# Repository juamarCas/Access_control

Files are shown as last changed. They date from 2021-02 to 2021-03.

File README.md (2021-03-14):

# Access Control
This project consist on a access control system. It uses microcontroller ESP8266 for internet connection, MQTT as my data transfer protocol, NodeJS as the backend programming Language, Express as the framework for the API and MySQL as the Database.</br>

The architecture of the complete project looks like this: </br>

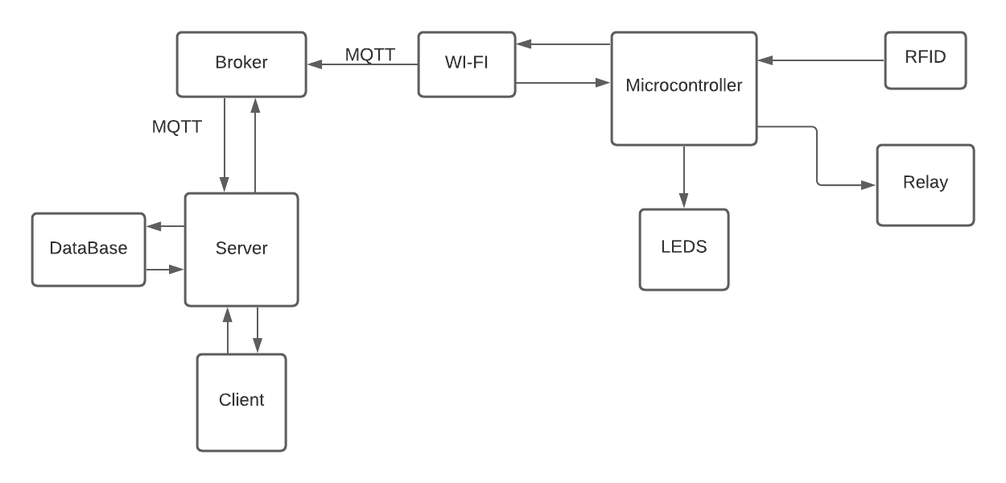
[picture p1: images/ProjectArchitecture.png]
all text


# Dockerizing
be executed with containers, for this, there is the _docker-compose.yml_ file, just copy the content of app.env.example and paste it in a new file called app.env same to the db.env.example and broker.env.example, then fill the data needed in both files, build the two Dockerfile that are in DataBase and webApp and then run the docker-compose.</br>
In the docker-compose file describes that the image used for the app is nodeapp, so be sure when the image is builded is named as that, or change its name as your needs, same for the image of the database.

# Directory
In this section I discribe briefly what is each folder.</br>

## Access_Control
In this folder is the microcontroller project and schematics, is programmed using the PIO IDE.</br>

## DataBase
Thise folder contains the sql file for creating the tables needed.</br>

## HW_Design
This folder includes the KiCad project for the circuit.</br>

## Web-client
This folder includes the frontend of the projects, hasn't started yet this part.</br>

## webApp
This folder includes the NodeJS code for the backend.</br>

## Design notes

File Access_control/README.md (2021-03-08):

# Access control circuit
This section shows the firmware of the microcontroller part of the project.</br>
Important note: The circuit uses a relay to activate the secure system, this is a security vulnerability, it can be brokenn with a magnetic attack, this problem can be solved changing the relay for another component like a transistor.</br>

## Running the circuit
1. There is a file called SecretsExample.h, create another file called secrets.h and copy the content from SecretsExample.h to secrets.h, then fill the parameters.
2. The file should look something like: 
```
#ifndef SECRETS_H   
#define SECRETS_H
#define _SSID "your ssid"
#define _PASS "your pass"
#define MQTT_SERVER "mqtt host/ip"
#define MQTT_PORT 1883
#define MQTT_SUBSCRIBE_TOPIC "bld1/apt6/room1/acc"
#define MQTT_PUBLIS_TOPIC "bld1/apt6/room1"
#define MQTT_USER "user_auth"
#define MQTT_PASS "pass_auth"
#define DEBUG 1
#endif
```
</br>
Important note: If you are not using MQTT access control, please skip MQTT_USER and MQTT_PASS, and in the main.cpp in _reconnect()_ method, delete the two parameters that are related to this definition.

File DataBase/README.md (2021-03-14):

# DataBase
MySQL version 5.7 </br>
Important Note: Using docker is not necessary, use another host of your needs.</br>

## Database design 

MySQL is the database used to store information and it follows this simplified design: </br>
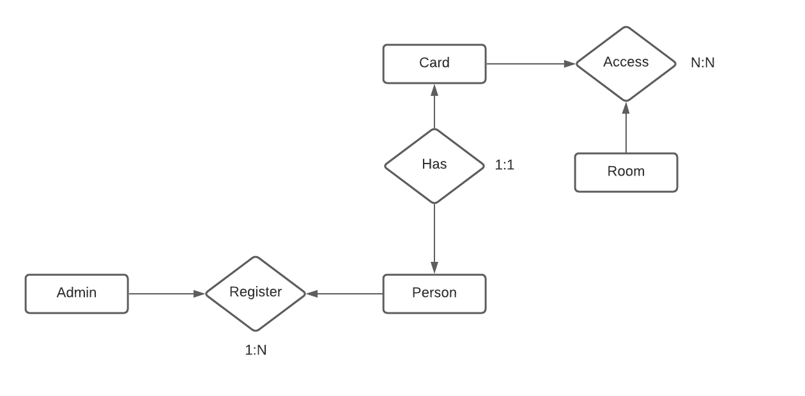
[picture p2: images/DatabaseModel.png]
all text Database model


## Tables
Important note:  the tables _mqtt\_user_ and _mqtt\_acl_ are for the EMQX MySQL access control plugin, if you are not using EMQX or the MySQL EQMX plugin, please skip those tables. For more information go to their [Documentation](https://docs.emqx.io/en/broker/latest/advanced/acl-mysql.html#mysql-connection-information "MySql access control plugin documentation").</br>

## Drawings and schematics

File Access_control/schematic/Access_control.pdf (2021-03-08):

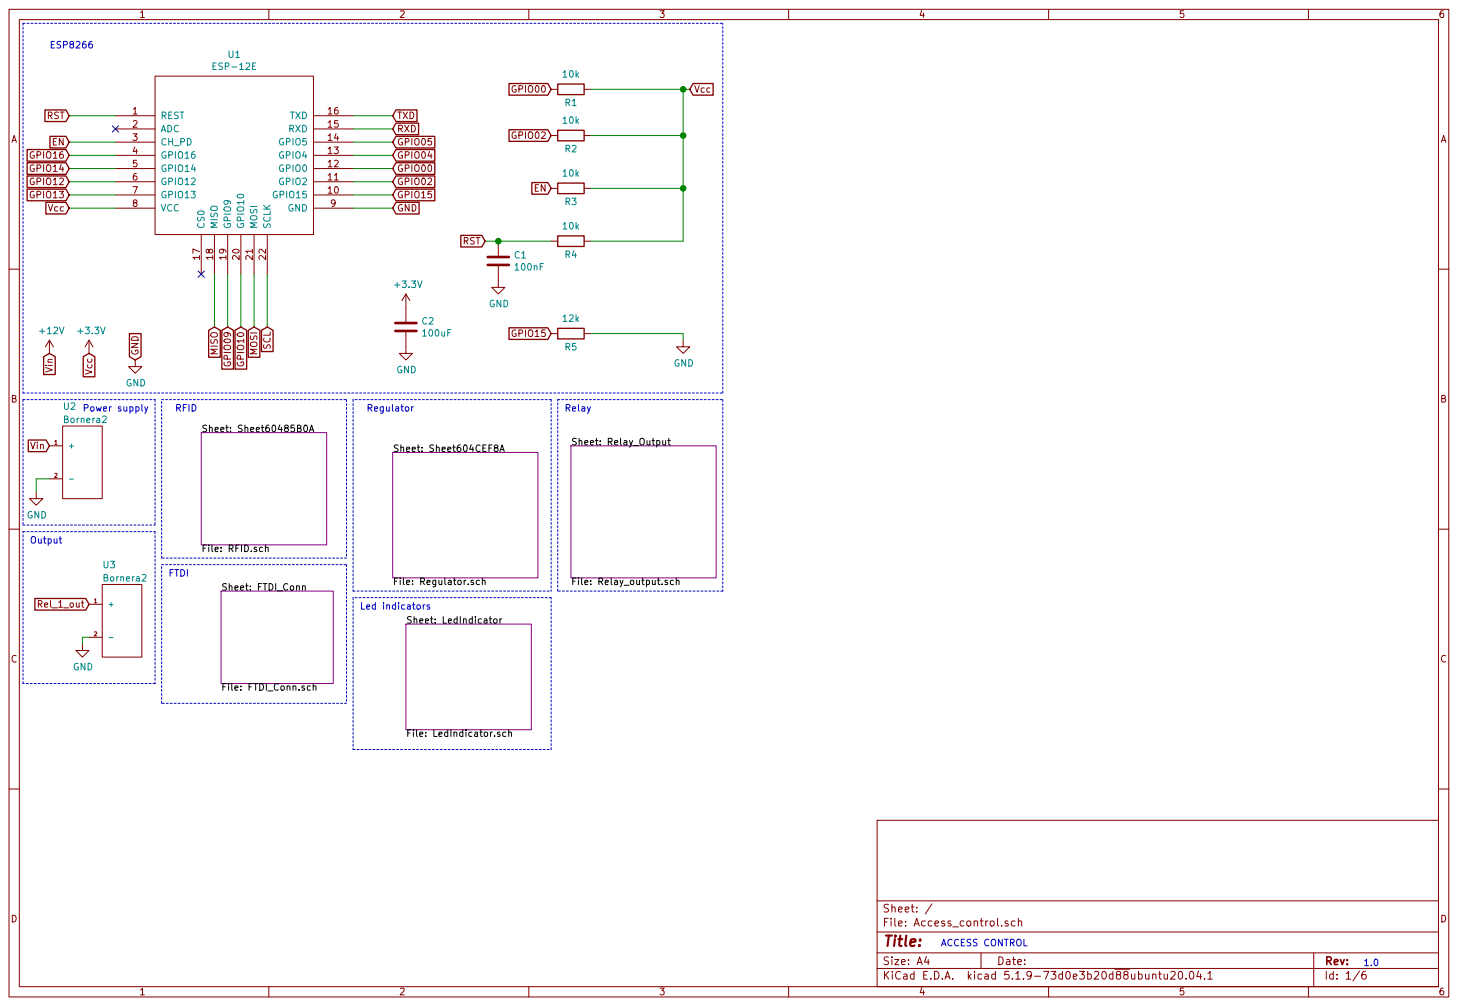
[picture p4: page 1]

File: Relay_output.sch Sheet: LedIndicator File: LedIndicator.sch GND

File: Regulator.sch Sheet: FTDI_Conn File: FTDI_Conn.sch Sheet: Sheet60485B0A

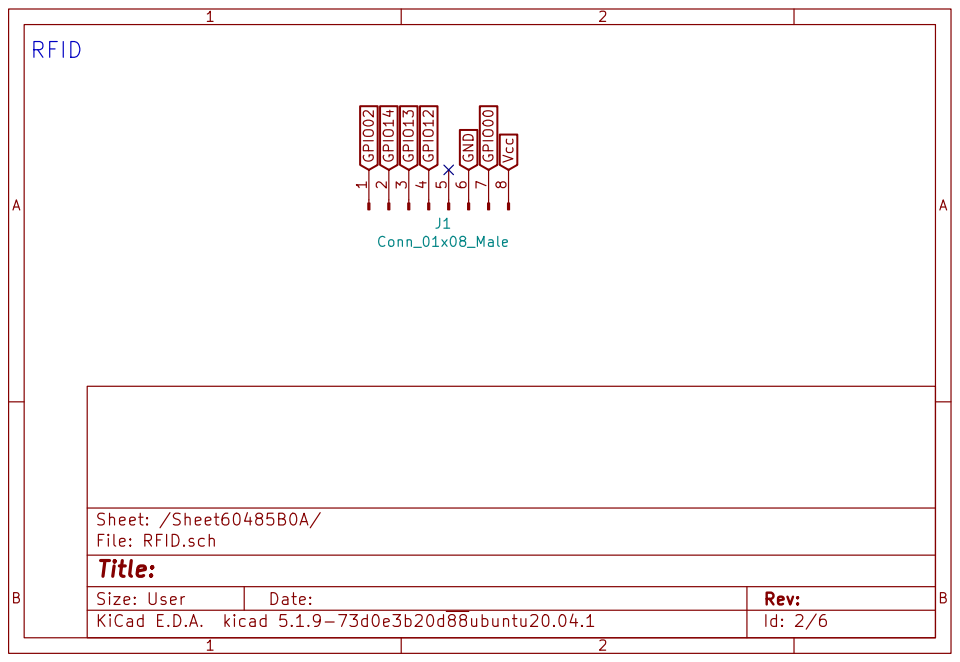
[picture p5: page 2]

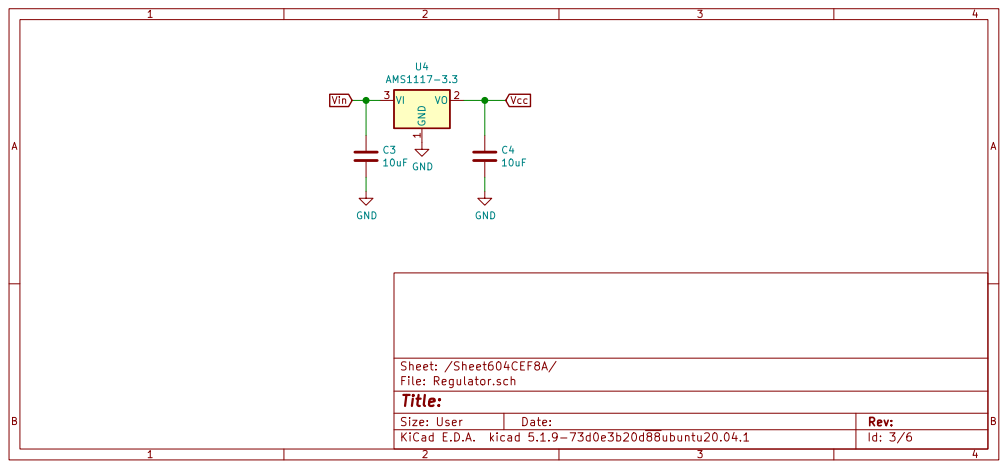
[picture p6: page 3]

File: Regulator.sch Sheet: /Sheet604CEF8A/ GNDGND

1 VO 2 VI 3 U4 AMS1117-3.3 GND GND

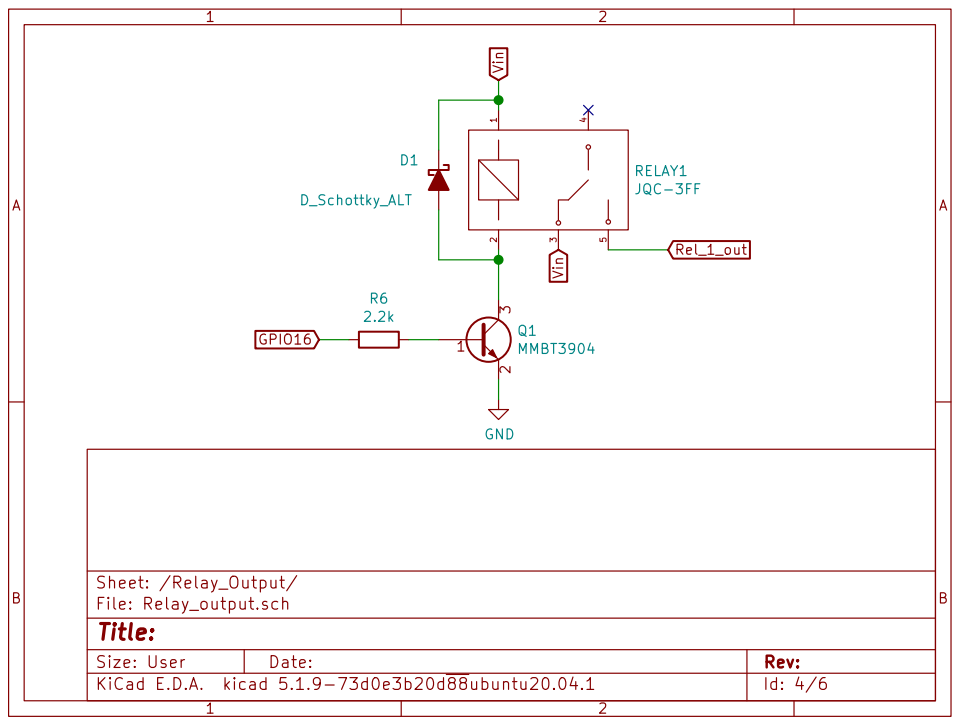
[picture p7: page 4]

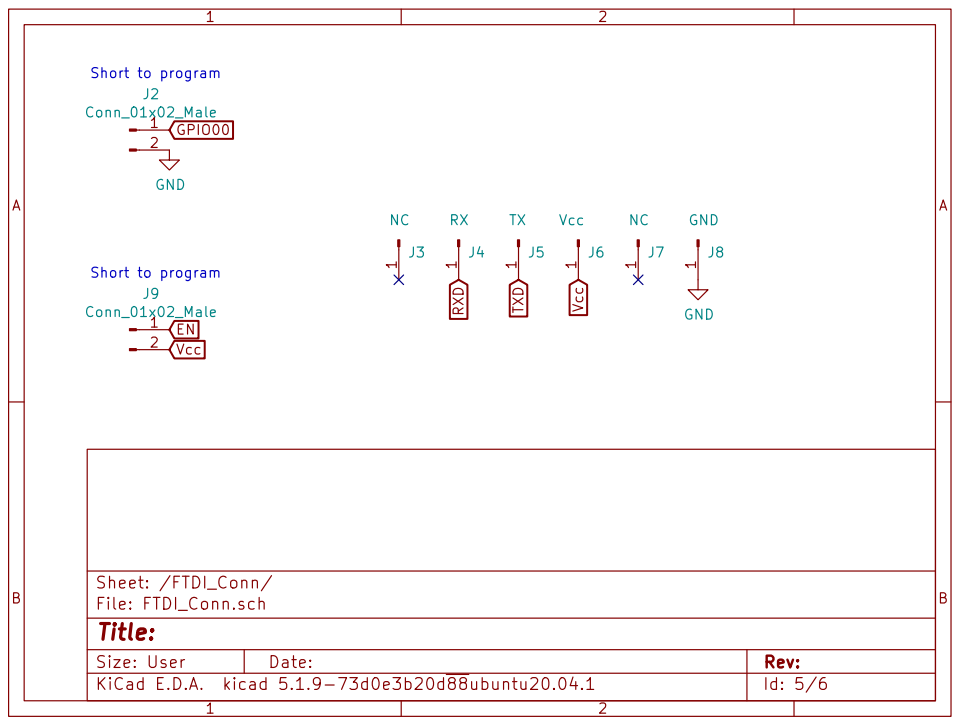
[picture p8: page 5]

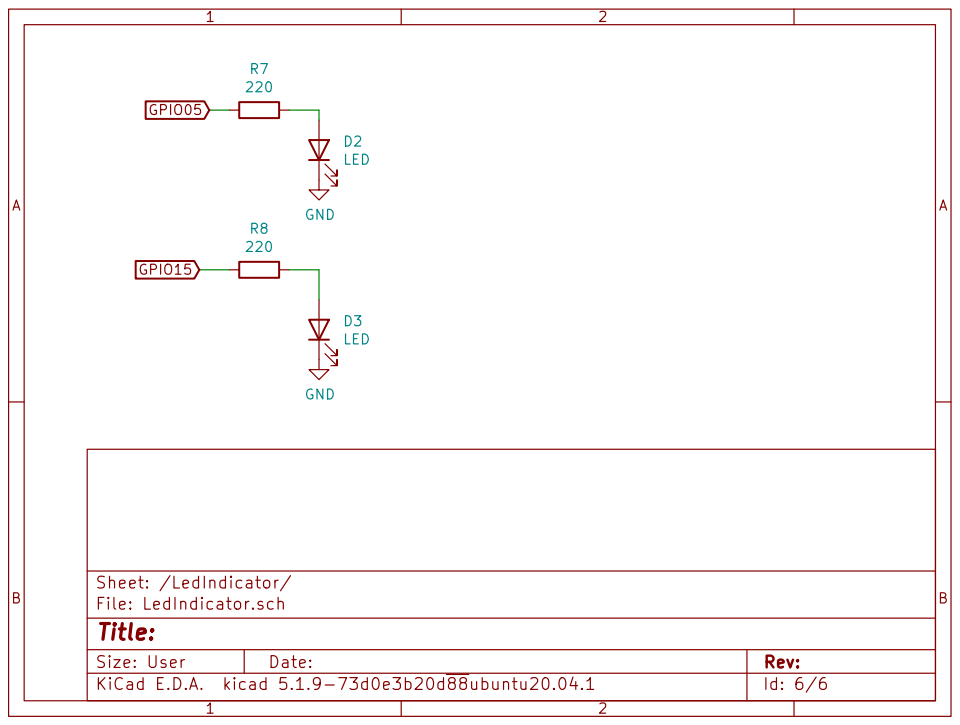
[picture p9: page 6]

Id: 6/6 Title: File: LedIndicator.sch Sheet: /LedIndicator/ R7

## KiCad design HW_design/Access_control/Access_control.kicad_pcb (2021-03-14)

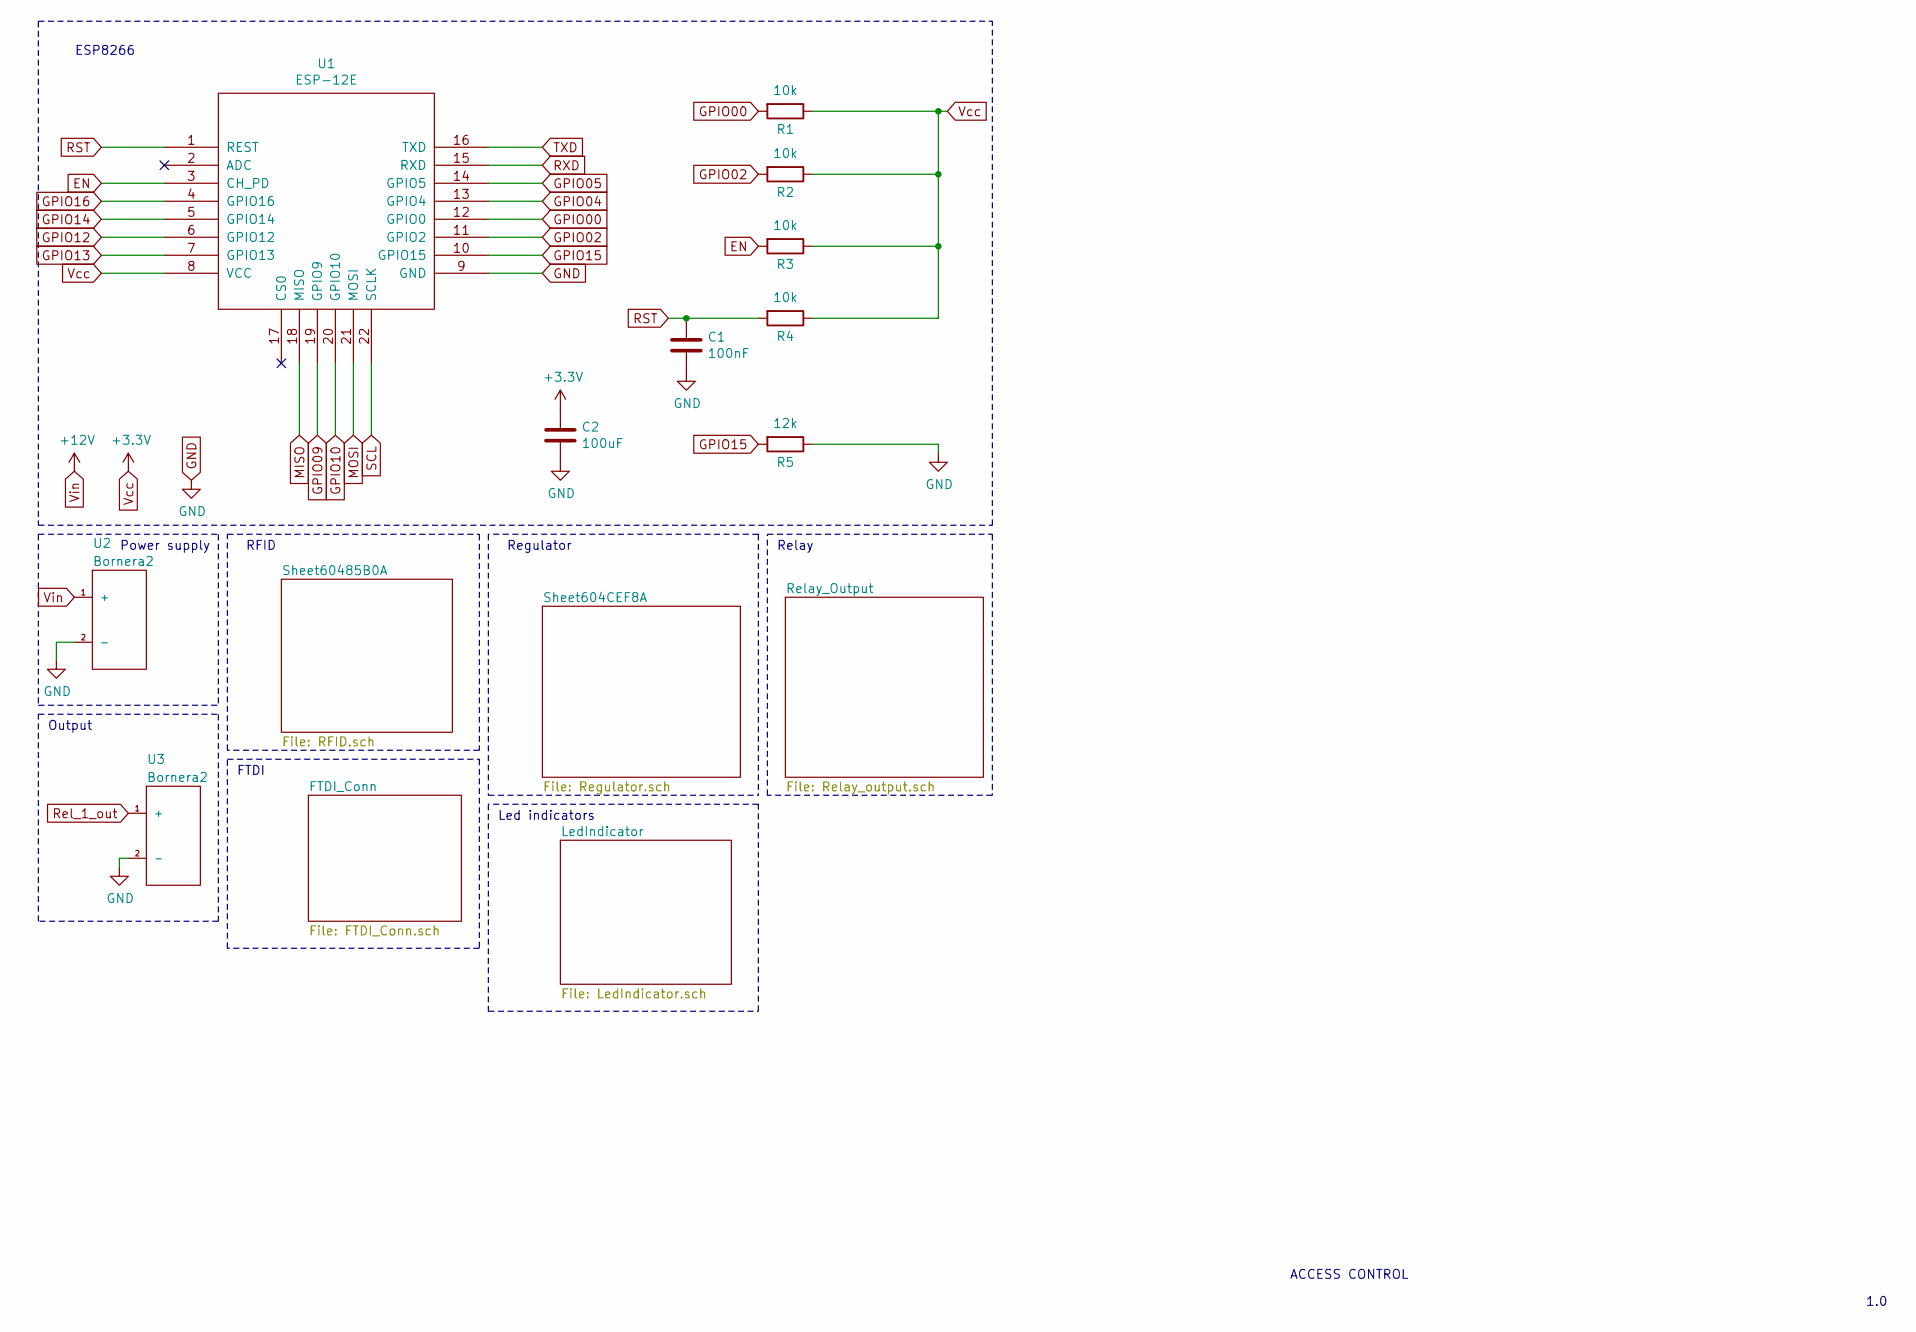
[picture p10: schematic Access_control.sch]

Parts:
C1: 100nF; C_1206_3216Metric
C2: 100uF; C_1206_3216Metric
R1, R2, R3, R4: 10k; R_0805_2012Metric
R5: 12k; R_0805_2012Metric
U1: ESP-12E; C_WiFiModule
U2, U3: Bornera2; Bronera_2

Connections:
EN: R3.2, U1.3 (CH_PD); also elsewhere on the board
GND: C1.2, C2.2, R5.1, U1.9 (GND), U2.2 (-), U3.2 (-); also elsewhere on the board
GPIO00: R1.2, U1.12 (GPIO0); also elsewhere on the board
GPIO02: R2.2, U1.11 (GPIO2); also elsewhere on the board
GPIO04: U1.13 (GPIO4)
GPIO05: U1.14 (GPIO5); also elsewhere on the board
GPIO09: U1.19 (GPIO9)
GPIO10: U1.20 (GPIO10)
GPIO12: U1.6 (GPIO12); also elsewhere on the board
GPIO13: U1.7 (GPIO13); also elsewhere on the board
GPIO14: U1.5 (GPIO14); also elsewhere on the board
GPIO15: R5.2, U1.10 (GPIO15); also elsewhere on the board
GPIO16: U1.4 (GPIO16); also elsewhere on the board
MISO: U1.18 (MISO)
MOSI: U1.21 (MOSI)
RST: C1.1, R4.2, U1.1 (REST)
RXD: U1.15 (RXD); also elsewhere on the board
Rel_1_out: U3.1 (+); also elsewhere on the board
SCL: U1.22 (SCLK)
TXD: U1.16 (TXD); also elsewhere on the board
Vcc: C2.1, R1.1, R2.1, R3.1, R4.1, U1.8 (VCC); also elsewhere on the board
Vin: U2.1 (+); also elsewhere on the board

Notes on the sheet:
ESP8266
RFID
Power supply
Regulator
ACCESS CONTROL
1.0
Relay
Output
FTDI
Led indicators

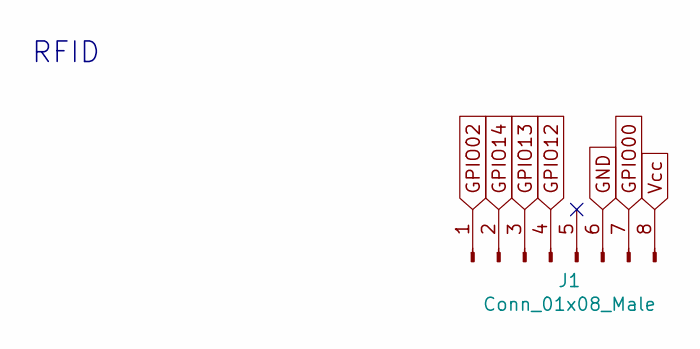
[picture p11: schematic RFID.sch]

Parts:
J1: Conn_01x08_Male; PinHeader_1x08_P2.54mm_Vertical

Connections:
GND: J1.6; also elsewhere on the board
GPIO00: J1.7; also elsewhere on the board
GPIO02: J1.1; also elsewhere on the board
GPIO12: J1.4; also elsewhere on the board
GPIO13: J1.3; also elsewhere on the board
GPIO14: J1.2; also elsewhere on the board
Vcc: J1.8; also elsewhere on the board

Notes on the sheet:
RFID

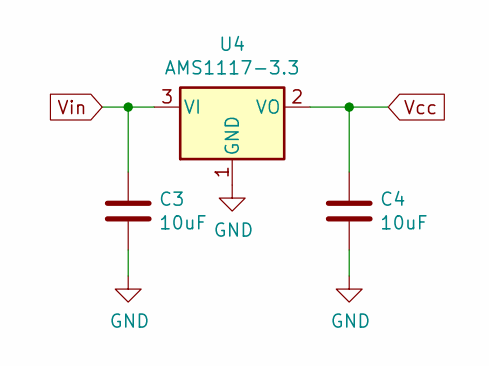
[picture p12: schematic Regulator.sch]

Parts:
C3, C4: 10uF; C_1206_3216Metric
U4: AMS1117-3.3; SOT-223-3_TabPin2

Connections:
GND: C3.2, C4.2, U4.1 (GND); also elsewhere on the board
Vcc: C4.1, U4.2 (VO); also elsewhere on the board
Vin: C3.1, U4.3 (VI); also elsewhere on the board

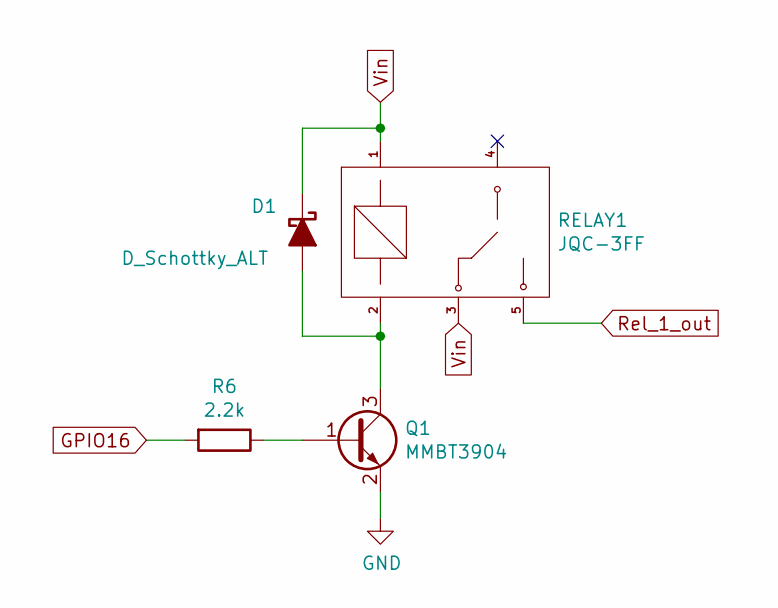
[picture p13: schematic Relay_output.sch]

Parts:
D1: D_Schottky_ALT; SMD_DIODE_4.6mmx2.90
Q1: MMBT3904; SOT-23
R6: 2.2k; R_0805_2012Metric
RELAY1: JQC-3FF; Relay

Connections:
GND: Q1.2 (E); also elsewhere on the board
GPIO16: R6.2; also elsewhere on the board
unnamed: D1.2 (A), Q1.3 (C), RELAY1.2
unnamed: Q1.1 (B), R6.1
Rel_1_out: RELAY1.5; also elsewhere on the board
Vin: D1.1 (K), RELAY1.1, RELAY1.3; also elsewhere on the board

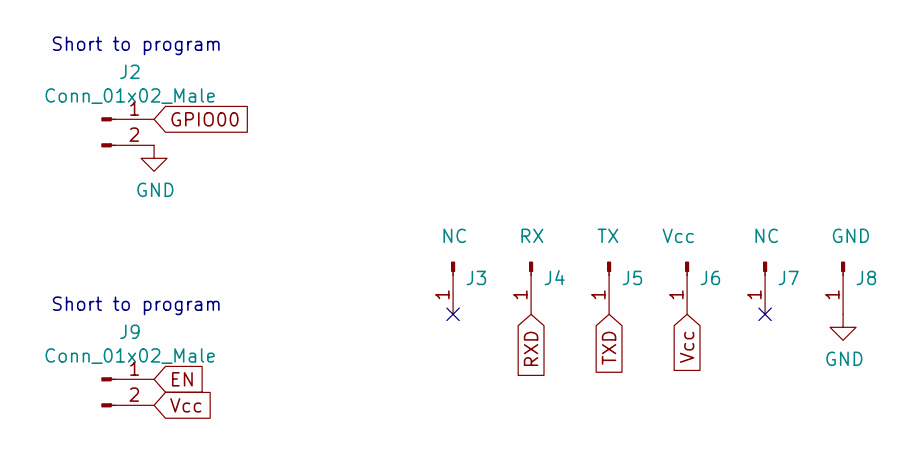
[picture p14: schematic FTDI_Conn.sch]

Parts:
J2, J9: Conn_01x02_Male; PinHeader_1x02_P2.54mm_Vertical
J3, J7: NC; PinHeader_1x01_P2.54mm_Vertical
J4: RX; PinHeader_1x01_P2.54mm_Vertical
J5: TX; PinHeader_1x01_P2.54mm_Vertical
J6: Vcc; PinHeader_1x01_P2.54mm_Vertical
J8: GND; PinHeader_1x01_P2.54mm_Vertical

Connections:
EN: J9.1; also elsewhere on the board
GND: J2.2, J8.1; also elsewhere on the board
GPIO00: J2.1; also elsewhere on the board
RXD: J4.1; also elsewhere on the board
TXD: J5.1; also elsewhere on the board
Vcc: J6.1, J9.2; also elsewhere on the board

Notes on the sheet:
Short to program

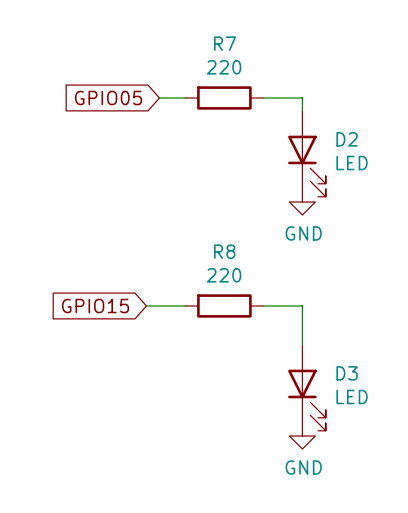
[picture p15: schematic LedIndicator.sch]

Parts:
D2, D3: LED; D_1206_3216Metric
R7, R8: 220; R_0805_2012Metric

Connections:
GND: D2.1 (K), D3.1 (K); also elsewhere on the board
GPIO05: R7.2; also elsewhere on the board
GPIO15: R8.2; also elsewhere on the board
unnamed: D2.2 (A), R7.1
unnamed: D3.2 (A), R8.1

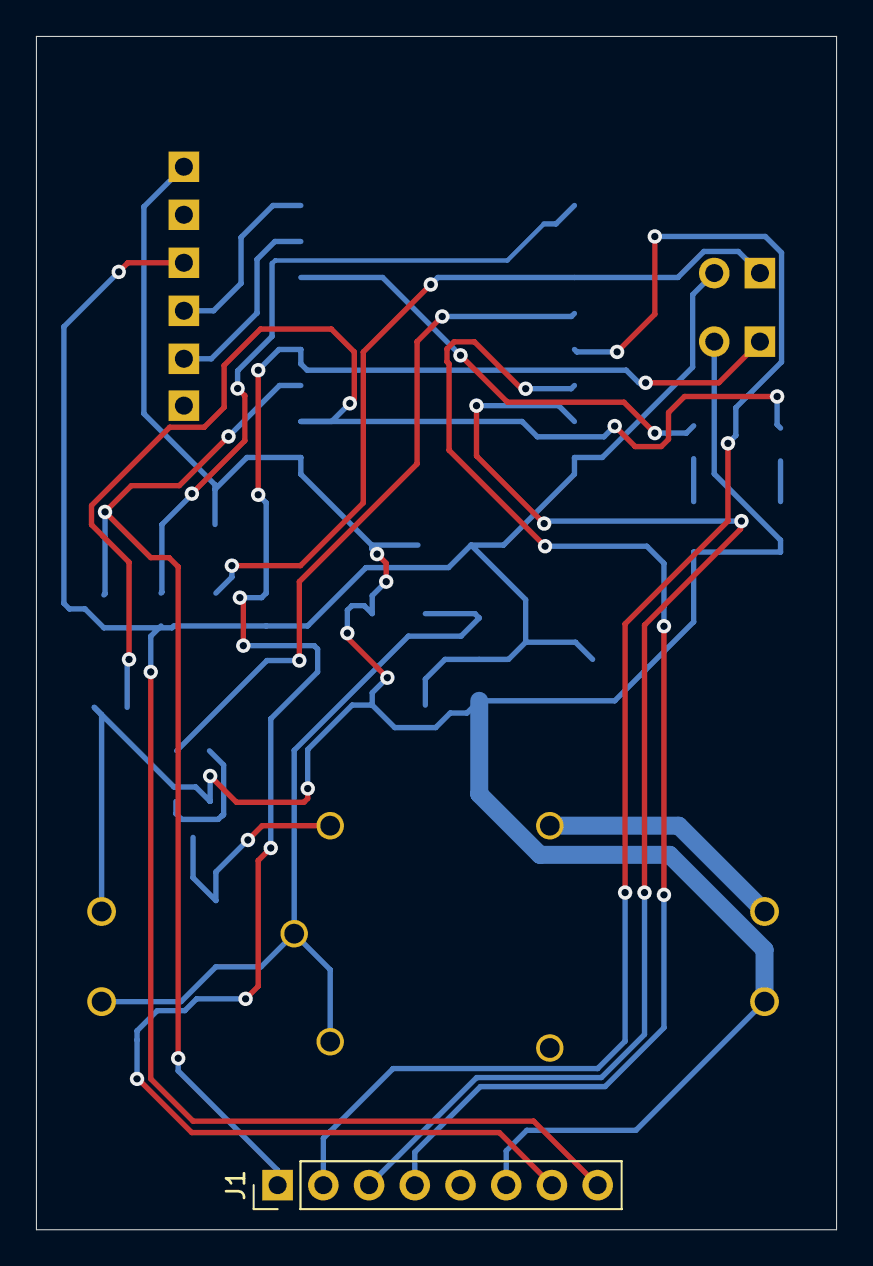
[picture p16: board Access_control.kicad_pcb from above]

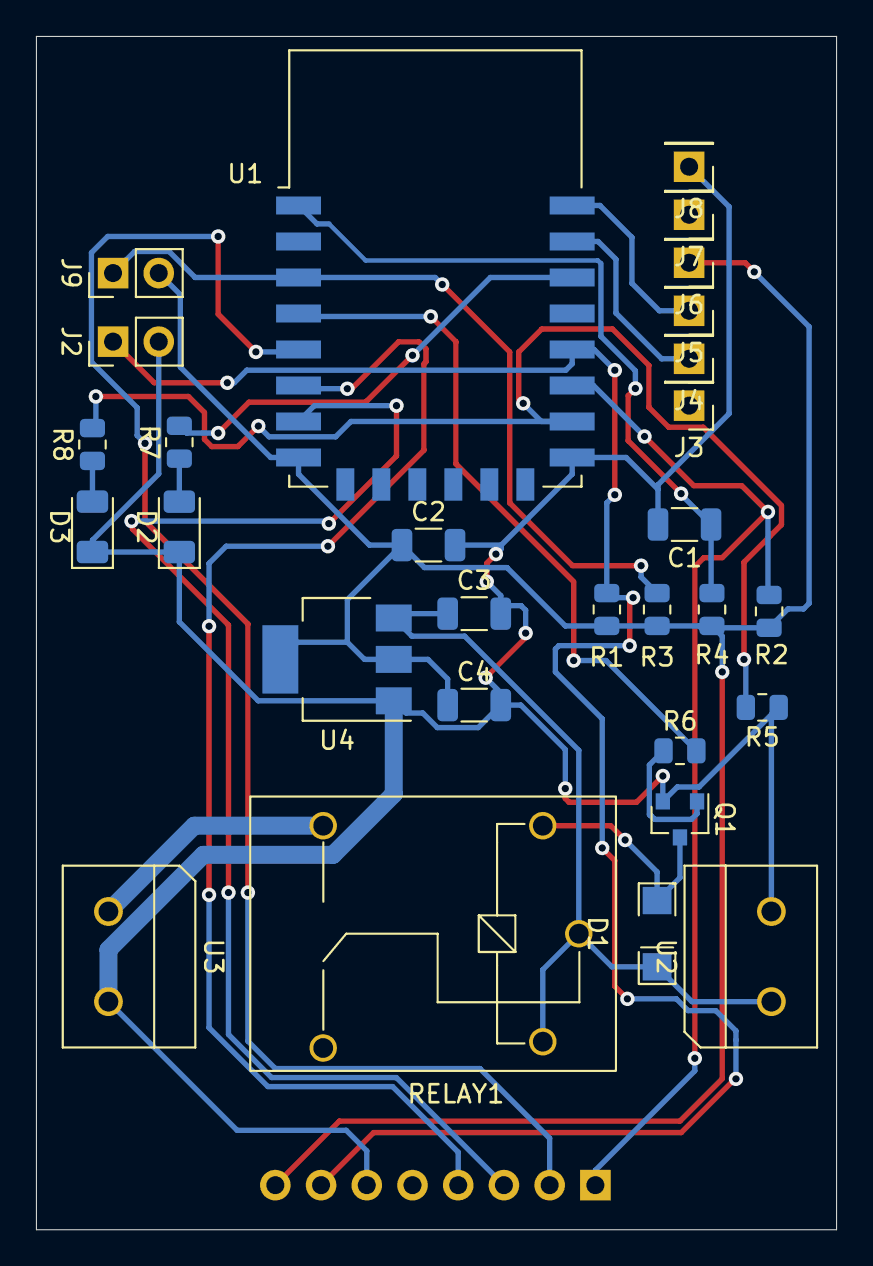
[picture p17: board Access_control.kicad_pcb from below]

Board: 2 copper layers, 44.4 x 66.3 mm, 30 parts (29 on the bottom side), 20 nets.

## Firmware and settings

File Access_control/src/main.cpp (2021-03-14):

#define _SSPIN D4
#define _RSTPIN D3
#define _ACCESS_DENIED_LED D1
#define _ACCESS_GRANTED_LED D0
#define _ACCESS_RELAY_PIN D0
#define DEBUG 1 //please, when you are going to release, turn this DEBUG to 0, like, #define DEBUG 0

#define waitTime 3000

#include <Arduino.h>
#include <SPI.h>

#include <CustomWiFi.h>
#include <PubSubClient.h>
#include <MFRC522.h>
#include <ArduinoJson.h>
#include <string>
bool hasPassed = false;

#if DEBUG
//Debug Variables if needed
#endif

MFRC522 acl(_SSPIN, _RSTPIN);
CustomWiFi cwifi;
WiFiClient deviceClient;
PubSubClient client(deviceClient);

void reconnect();
void SendData(String data);
void callback(char *topic, byte *payload, unsigned int lenght);

const int capacity = JSON_OBJECT_SIZE(4) + 35;
DynamicJsonBuffer doc(capacity);
JsonObject &root = doc.createObject();

#if DEBUG
//Debug functions if needed
void ShowReaderDetails();
#endif

void setup()
{
  SPI.begin();
  acl.PCD_Init();
  cwifi.begin();
  client.setServer(MQTT_SERVER, MQTT_PORT);
  client.setCallback(callback);
  pinMode(_ACCESS_DENIED_LED, OUTPUT);
  pinMode(_ACCESS_GRANTED_LED, OUTPUT);
//serial begin is in the CustomWiFiLibrary
#if DEBUG
  Serial.println("");
  Serial.println("Access control WiFi module v 1.0");
  ShowReaderDetails();
#endif
}

void loop()
{
#if DEBUG
  //testing GPIOs
#endif

  if (!client.connected())
  {
    reconnect();
  }

  client.loop();
  if (!acl.PICC_IsNewCardPresent())
    return; //Im not detecting any card
  if (!acl.PICC_ReadCardSerial())
    return; //I cant obtain the code for this card
  if (!hasPassed)
  {
    hasPassed = true;
    String data = "";
    for (byte i = 0; i < 4; i++)
    {
      data += String(acl.uid.uidByte[i]);
    }

    SendData(data);
#if DEBUG
    Serial.println(data);
#endif
  }
}

void reconnect()
{
  while (!client.connected())
  {
#if DEBUG
    Serial.println("Trying to reconnect to MQTT");
#endif

    String clientID = "esp8266_";
    clientID += String(random(0xffff), HEX);
    if (client.connect(clientID.c_str(), MQTT_USER, MQTT_PASS))
    {
      client.subscribe("bld1/apt6/room1/acc");
    }
    else
    {
      delay(1000);
    }
  }
}

void SendData(String Data)
{
  //Sending data in JSON Format
  /*
  JSON sent format example:
  {
    "type":"access", 
    "card":"1234567", 
    "room": "room_001"
  }
  */
  root["type"].set("access");
  root["card"].set(Data);
  root["room"].set(ROOM_ID);
  char jsonChar[100];
  root.printTo((char *)jsonChar, root.measureLength() + 1);
  client.publish("bld1/apt6/room1", jsonChar);
}

void callback(char *topic, byte *payload, unsigned int lenght)
{

  String incomming = "";
  for (unsigned int i = 0; i < lenght; i++)
  {
    incomming += (char)payload[i];
  }


  //Deserializing the JSON incomming from the server
  char buff[100]; 
  incomming.toCharArray(buff, 100); 
  JsonObject &obj = doc.parseObject(buff);
  
  /*
  this is the JSON format incomming example: 
  {
    "status": "off"
  }
  */
  if (obj.success())
  {
    auto status = obj["status"].as<char *>();
    const char *onStatus = "on";
    Serial.println(status); 
    if (strcmp(status, onStatus) == 0)
    {
      digitalWrite(_ACCESS_GRANTED_LED, HIGH);
      digitalWrite(_ACCESS_RELAY_PIN, HIGH);
    }
    else
    {
      digitalWrite(_ACCESS_DENIED_LED, HIGH);
    }
    delay(waitTime);

    digitalWrite(_ACCESS_GRANTED_LED, LOW);
    digitalWrite(_ACCESS_RELAY_PIN, LOW);
    digitalWrite(_ACCESS_DENIED_LED, LOW);
  }
  else
  {
#if DEBUG
    Serial.println("Does not parse");
#endif
  }
    hasPassed = false;
}

#if DEBUG
void ShowReaderDetails()
{
  // Get the MFRC522 software version
  byte v = acl.PCD_ReadRegister(acl.VersionReg);
  Serial.print(F("MFRC522 Software Version: 0x"));
  Serial.print(v, HEX);
  if (v == 0x91)
    Serial.print(F(" = v1.0"));
  else if (v == 0x92)
    Serial.print(F(" = v2.0"));
  else
    Serial.print(F(" (unknown),probably a chinese clone?"));
  Serial.println("");
  // When 0x00 or 0xFF is returned, communication probably failed
  if ((v == 0x00) || (v == 0xFF))
  {
    Serial.println(F("WARNING: Communication failure, is the MFRC522 properly connected?"));
    Serial.println(F("SYSTEM HALTED: Check connections."));
    while (true); // do not go further
  }
}
#endif

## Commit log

2021-02-12 implemented mysql auth to the broker
    [main.cpp]
2021-03-06 Schematic update
    [Access_control.sch, FTDI_Conn.sch, LedIndicator.sch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]
2021-03-07 pcb design
    [Access_control.kicad_pcb, Access_control.sch, FTDI_Conn.sch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]
2021-03-07 fix pcb
    [Access_control.kicad_pcb]
2021-03-14 Added JSON support microcontroller
    [Access_control.kicad_pcb]
